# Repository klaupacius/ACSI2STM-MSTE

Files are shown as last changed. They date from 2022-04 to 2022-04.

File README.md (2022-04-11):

# ACSI2STM-MSTE
 
This a KiCAD (6.0) design to host an [ACSI2STM](https://github.com/retro16/acsi2stm) directly inside an Atari Mega STE using the internal connector. 
The PCB has been designed to accomodate version 2.43 of ACSI2STM (aka V2) but also the V1 design as sold by @masteries on AtariAge. 
- No external power is required, the 5v is taken directly from the internal ACSI connector, but this has only been tested with a fully recapped PSU. 
- A set of jumper needs to be soldered to configure the board for V1 or V2 as noted on the PCB.

:warning: **DO NOT PLUG ANY USB CABLE ON THE STM32 ONCE INSTALLED IN THE MEGA STE** :warning:

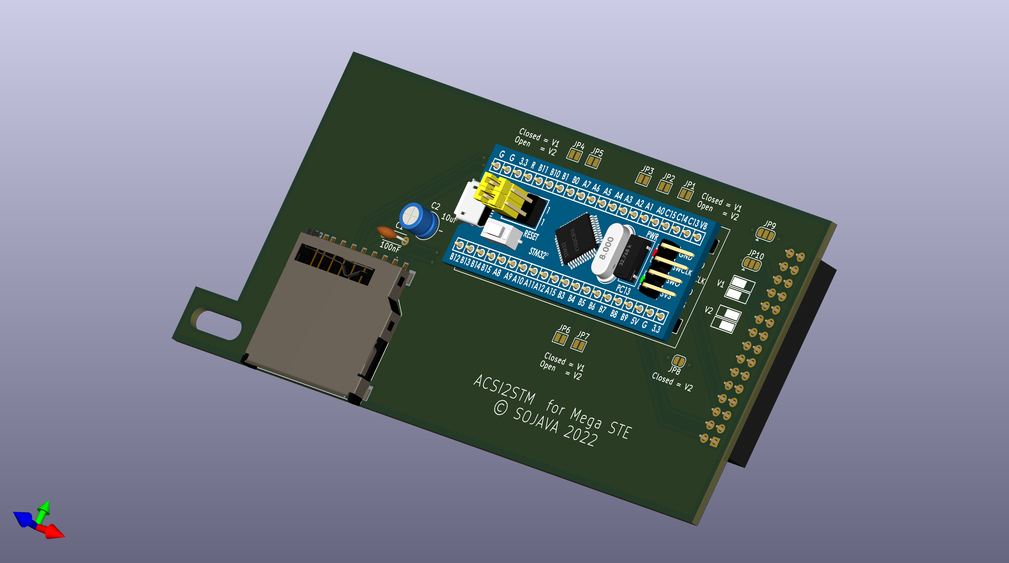
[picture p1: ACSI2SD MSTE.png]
ACSI2STM Adapter render


## BOM
- 100 nF Capacitor
- 10uF Radial Capacitor
- Female 2.54 headers
- Amphenol GSD090012SEU SD Card socket
- STM32F103C8T6 "Blue Pill" (original one is highly recommended!!!). 
- Firmware from [ACSI2STM](https://github.com/retro16/acsi2stm) or from @masteries. 

## Configuration
Configuration is done by simple solder bridges on the pads, instructions are also written on PCB.

### For V1:
- Solder bridge: JP1, JP2, JP3, JP4, JP5, JP6, JP7
- Solder bridge pads 1 and 2 of JP9 (2 leftmost pads)
- Solder bridge pads 1 and 2 of JP10 (2 leftmost pads)

### For V2: 
- Solder bridge pads 2 and 3 of JP9 (2 leftmost pads)
- Solder bridge pads 2 and 3 of JP10 (2 leftmost pads)
- Solder bridge JP8 (optional but recommended)

:warning: **DO NOT PLUG ANY USB CABLE ON THE STM32 ONCE INSTALLED IN THE MEGA STE** :warning:

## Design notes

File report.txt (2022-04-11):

Plotted to '/Users/ojan/Documents/Kicad/ACSI2SD MSTE/Output/ACSI2SD MSTE-F_Cu.gbr'.
Plotted to '/Users/ojan/Documents/Kicad/ACSI2SD MSTE/Output/ACSI2SD MSTE-B_Cu.gbr'.
Plotted to '/Users/ojan/Documents/Kicad/ACSI2SD MSTE/Output/ACSI2SD MSTE-F_Paste.gbr'.
Plotted to '/Users/ojan/Documents/Kicad/ACSI2SD MSTE/Output/ACSI2SD MSTE-B_Paste.gbr'.
Plotted to '/Users/ojan/Documents/Kicad/ACSI2SD MSTE/Output/ACSI2SD MSTE-F_Silkscreen.gbr'.
Plotted to '/Users/ojan/Documents/Kicad/ACSI2SD MSTE/Output/ACSI2SD MSTE-B_Silkscreen.gbr'.
Plotted to '/Users/ojan/Documents/Kicad/ACSI2SD MSTE/Output/ACSI2SD MSTE-F_Mask.gbr'.
Plotted to '/Users/ojan/Documents/Kicad/ACSI2SD MSTE/Output/ACSI2SD MSTE-B_Mask.gbr'.
Plotted to '/Users/ojan/Documents/Kicad/ACSI2SD MSTE/Output/ACSI2SD MSTE-Edge_Cuts.gbr'.
Created Gerber job file '/Users/ojan/Documents/Kicad/ACSI2SD MSTE/Output/ACSI2SD MSTE-job.gbrjob'.
Info: Done.

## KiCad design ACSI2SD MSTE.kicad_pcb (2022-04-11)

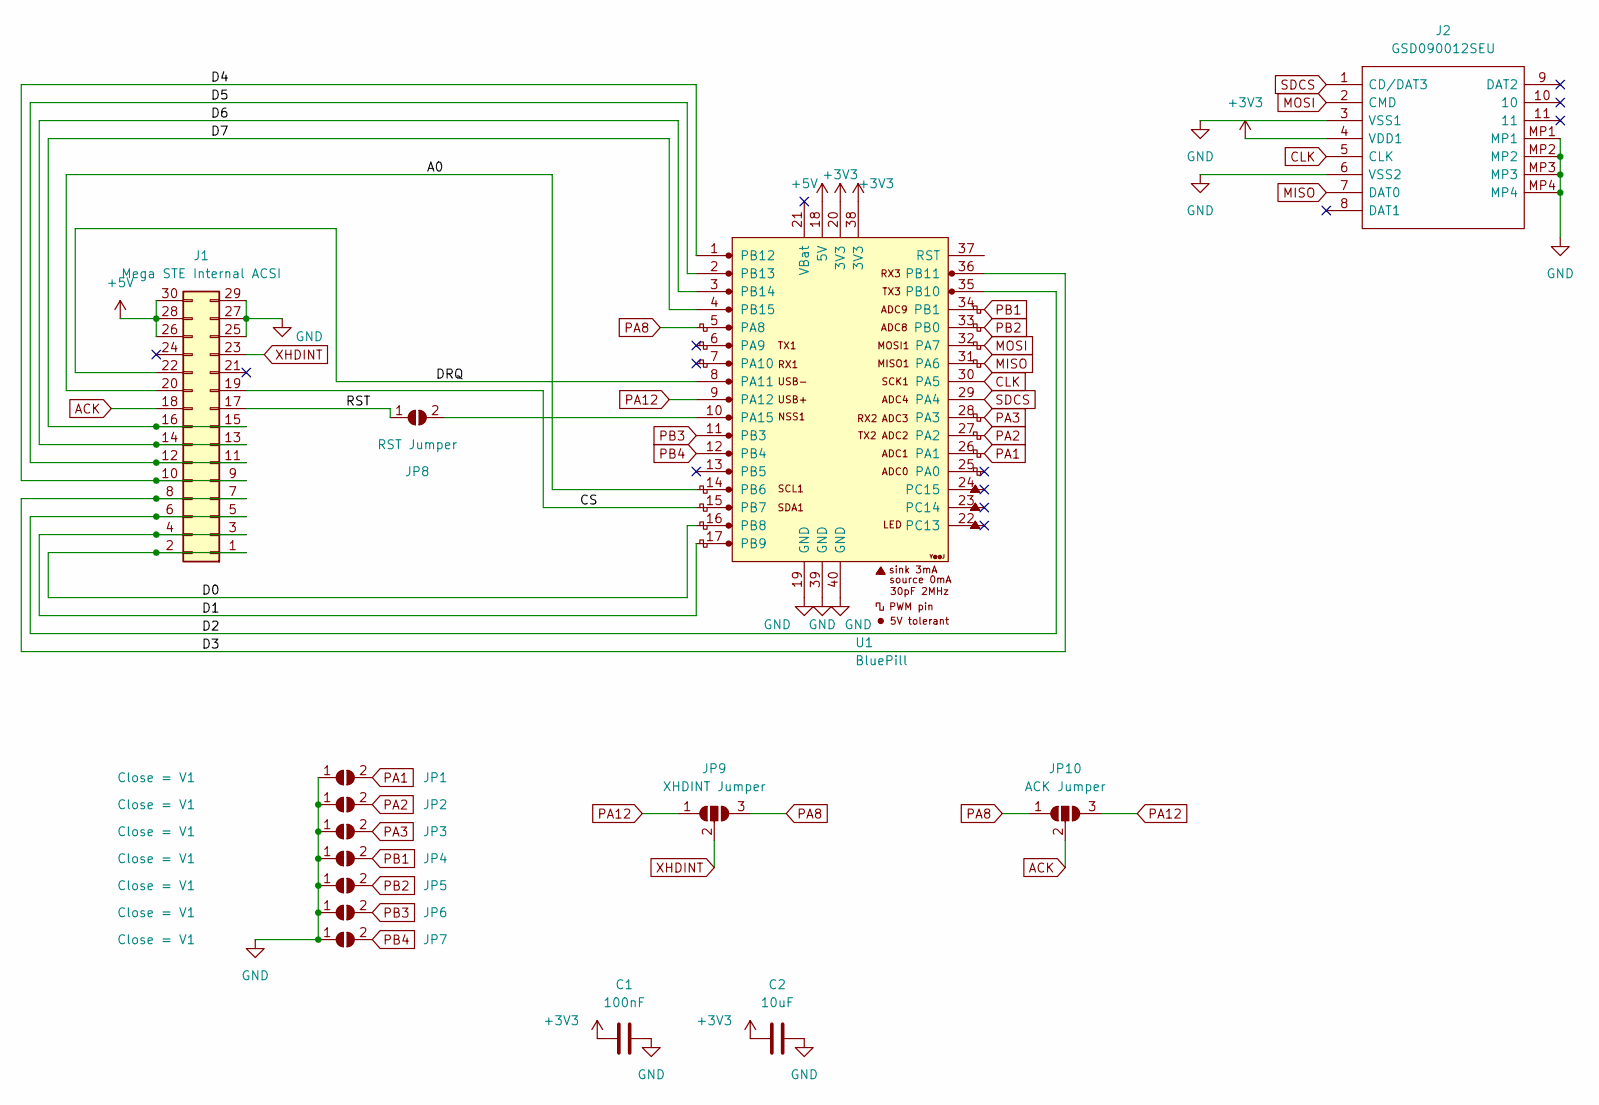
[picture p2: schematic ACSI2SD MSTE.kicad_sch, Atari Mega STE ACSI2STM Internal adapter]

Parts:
C1: 100nF; C_Disc_D4.3mm_W1.9mm_P5.00mm
C2: 10uF; C_Radial_D5.0mm_H5.0mm_P2.00mm
J1: Mega STE Internal ACSI; PinSocket_2x15_P2.54mm_Vertical
J2: GSD090012SEU; Mouser Part Number 523-GSD090012SEU
JP1, JP2, JP3, JP4, JP5, JP6, JP7: Close = V1; SolderJumper-2_P1.3mm_Open_Pad1.0x1.5mm
JP8: RST Jumper; SolderJumper-2_P1.3mm_Open_RoundedPad1.0x1.5mm
JP9: XHDINT Jumper; SolderJumper-3_P1.3mm_Open_RoundedPad1.0x1.5mm
JP10: ACK Jumper; SolderJumper-3_P1.3mm_Open_RoundedPad1.0x1.5mm
U1: BluePill; YAAJ_BluePill_1

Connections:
+3V3: C1.1, C2.1, J2.4 (VDD1), U1.20 (3V3), U1.38 (3V3)
+5V: J1.26, J1.28, J1.30, U1.18 (5V)
/A0: J1.20, U1.14 (PB6)
/CS: J1.19, U1.15 (PB7)
/D0: J1.1, J1.2, U1.16 (PB8)
/D1: J1.3, J1.4, U1.17 (PB9)
/D2: J1.5, J1.6, U1.35 (PB10)
/D3: J1.7, J1.8, U1.36 (PB11)
/D4: J1.9, J1.10, U1.1 (PB12)
/D5: J1.11, J1.12, U1.2 (PB13)
/D6: J1.13, J1.14, U1.3 (PB14)
/D7: J1.15, J1.16, U1.4 (PB15)
/DRQ: J1.22, U1.8 (PA11)
/RST: J1.17, JP8.1 (A)
ACK: J1.18, JP10.2 (C)
CLK: J2.5 (CLK), U1.30 (PA5)
GND: C1.2, C2.2, J1.25, J1.27, J1.29, J2.3 (VSS1), J2.6 (VSS2), J2.MP1, J2.MP2, J2.MP3, J2.MP4, JP1.1 (A), JP2.1 (A), JP3.1 (A), JP4.1 (A), JP5.1 (A), JP6.1 (A), JP7.1 (A), U1.19 (GND), U1.39 (GND), U1.40 (GND)
MISO: J2.7 (DAT0), U1.31 (PA6)
MOSI: J2.2 (CMD), U1.32 (PA7)
unnamed: JP8.2 (B), U1.10 (PA15)
PA1: JP1.2 (B), U1.26 (PA1)
PA2: JP2.2 (B), U1.27 (PA2)
PA3: JP3.2 (B), U1.28 (PA3)
PA8: JP9.3 (B), JP10.1 (A), U1.5 (PA8)
PA12: JP9.1 (A), JP10.3 (B), U1.9 (PA12)
PB1: JP4.2 (B), U1.34 (PB1)
PB2: JP5.2 (B), U1.33 (PB0)
PB3: JP6.2 (B), U1.11 (PB3)
PB4: JP7.2 (B), U1.12 (PB4)
SDCS: J2.1 (CD/DAT3), U1.29 (PA4)
XHDINT: J1.23, JP9.2 (C)

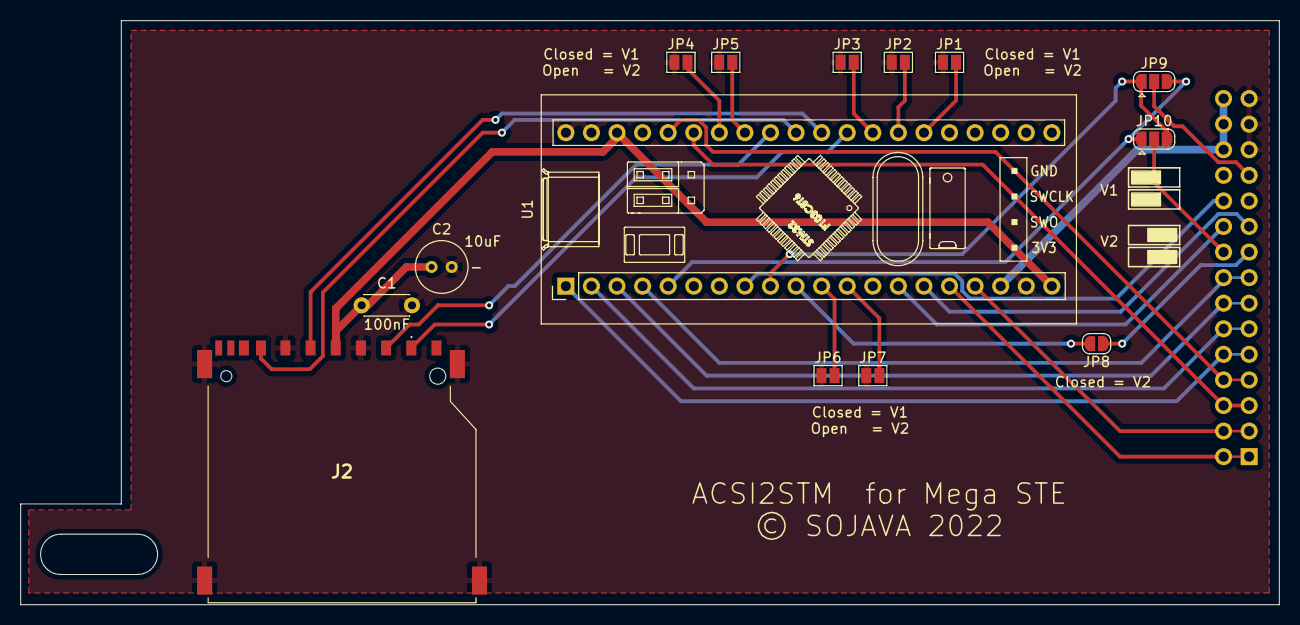
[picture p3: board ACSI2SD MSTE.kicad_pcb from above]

Board: 2 copper layers, 125.0 x 58.0 mm, 15 parts (1 on the bottom side), 31 nets.

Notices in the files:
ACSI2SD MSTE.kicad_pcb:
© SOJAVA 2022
